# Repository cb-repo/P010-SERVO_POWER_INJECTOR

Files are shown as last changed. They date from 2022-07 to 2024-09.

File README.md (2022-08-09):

# SERVO POWER INJECTOR / BEC v1.0

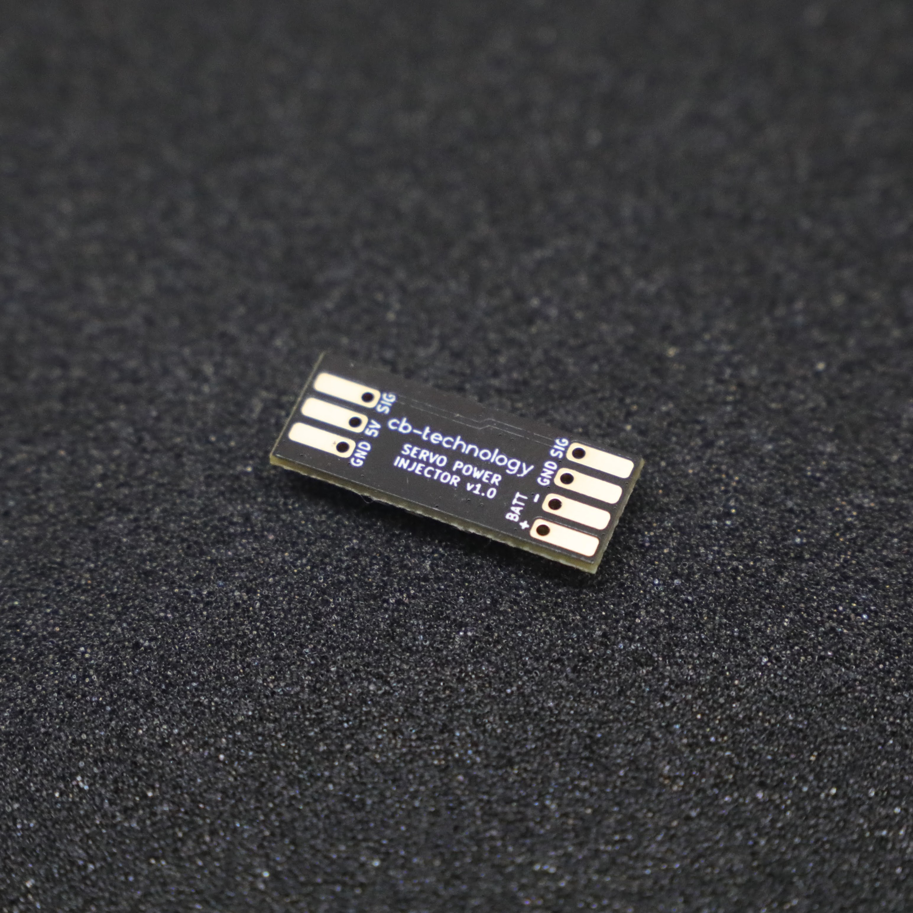
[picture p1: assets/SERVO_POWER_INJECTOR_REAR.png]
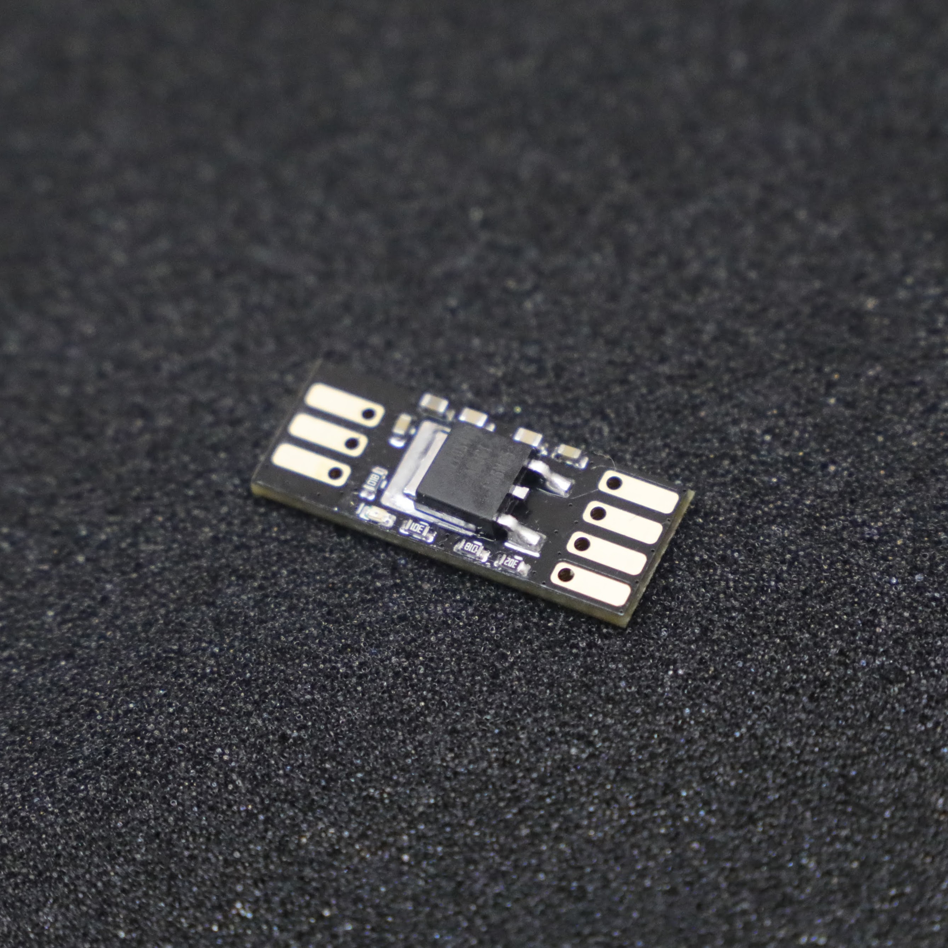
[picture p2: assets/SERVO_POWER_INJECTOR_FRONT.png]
   

SERVO POWER INJECTOR is a light-weight high-current power supply that is designed to regulate a battery input down to 5V and splice that into the standard pinout used by most hobby servo's. Originally this product was designed for combat robotics, but it's suitable for any application that requires a compact 5V power supply. 

This product can also be used as a standard Micro BEC by not connecting the signal I/O (just using the Battery input and 5V out).
When operating in this mode, there are no comprimises with size or weight, infact having a higher current output and additional features, when compared to simmilar BEC products.

This is a [New Zealand](https://www.google.co.nz/maps/place/Christchurch+New+Zealand) based product by [cb-technology](https://www.cb-technology.co.nz/), Connor Benton.

## FEATURES

- High current rating to allow reliable operation of most hobby servo's (mitigating risk of brown out).
- Small form-factor and lightweight design to integrate easily into systems that may be size or weight constrained. 
- Integrated thermal and current limiting.
- Power LED on 5V output to indicate when downstream electronics are armed.
- Red power LED colour chosen for its visibility.
- Incase of a fault, protection is added to the signal line to minimise cascading failures in the system.

## SPECIFICATIONS
- **Dimensions:** 11x28x4 mm
- **Weight:** 2 g
- **Input Voltage - Rated:** 6-12.6 V (2-3S LiPo)
- **Input Voltage - Absolute Max:** 13.2 V
- **Current - Rated:** 5 A
- **Current - Max:** 6.5 A

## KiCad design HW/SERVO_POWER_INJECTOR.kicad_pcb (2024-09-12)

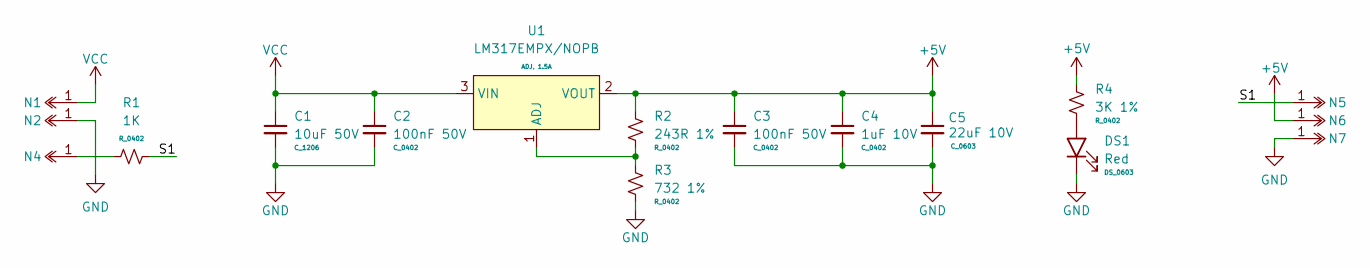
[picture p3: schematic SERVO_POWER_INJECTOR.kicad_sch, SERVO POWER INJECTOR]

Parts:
C1: 10uF 50V; C_1206; MFG Part FCC1206X106K500HT; LCSC Part C7467044
C2, C3: 100nF 50V; C_0402; MFG Part FCC0402B104K500AT; LCSC Part C5137492
C4: 1uF 10V; C_0402; MFG Part FCC0402X105K100AT; LCSC Part C5137473
C5: 22uF 10V; C_0603; MFG Part CL10A226MP8NUNE; LCSC Part C86295
DS1: Red; DS_0603; MFG Part XL-1608SURC-06; LCSC Part C965799
N1, N2, N4, N5, N6, N7: Finger_2.5x4_M1
R1: 1K; R_0402
R2: 243R 1%; R_0402; MFG Part FRC0402F2430TS; LCSC Part C2929995
R3: 732 1%; R_0402; MFG Part RC0402FR-07732RL; LCSC Part C137939
R4: 3K 1%; R_0402; MFG Part FRC0402F3001TS; LCSC Part C2909355
U1: LM317EMPX/NOPB; SOT223_3

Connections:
+5V: C3.1, C4.1, C5.1, N6.1, R2.1, R4.1, U1.2 (VOUT)
/S1: N5.1, R1.2
GND: C1.2, C2.2, C3.2, C4.2, C5.2, DS1.1 (K), N2.1, N7.1, R3.2
unnamed: DS1.2 (A), R4.2
unnamed: N4.1, R1.1
unnamed: R2.2, R3.1, U1.1 (ADJ)
VCC: C1.1, C2.1, N1.1, U1.3 (VIN)

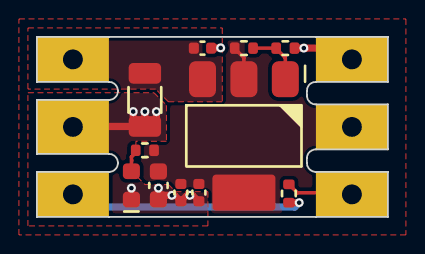
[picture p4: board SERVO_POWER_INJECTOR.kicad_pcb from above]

Board: 2 copper layers, 19.5 x 10.0 mm, 17 parts (0 on the bottom side), 7 nets.

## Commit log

2022-07-07 Generate first revision servo power injector
    [SERVO_POWER_INJECTOR-B_Courtyard.gbr, SERVO_POWER_INJECTOR-B_Cu.gbr, SERVO_POWER_INJECTOR-B_Fab.gbr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]
2024-09-12 WIP Commit
    [SERVO_POWER_INJECTOR.kicad_pcb, SERVO_POWER_INJECTOR.kicad_sch]
